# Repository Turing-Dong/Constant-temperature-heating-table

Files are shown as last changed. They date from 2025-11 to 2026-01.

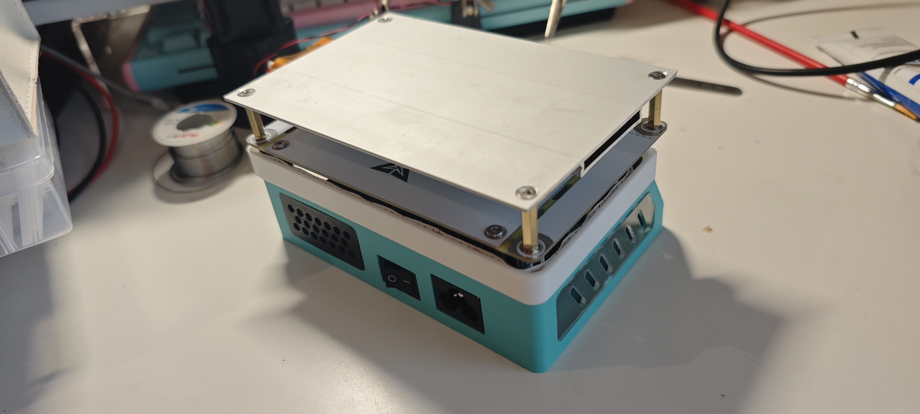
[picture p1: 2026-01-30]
project_v1.2/image/f8bacf540ac5dc9dfccfac3b2e75b12f.jpg

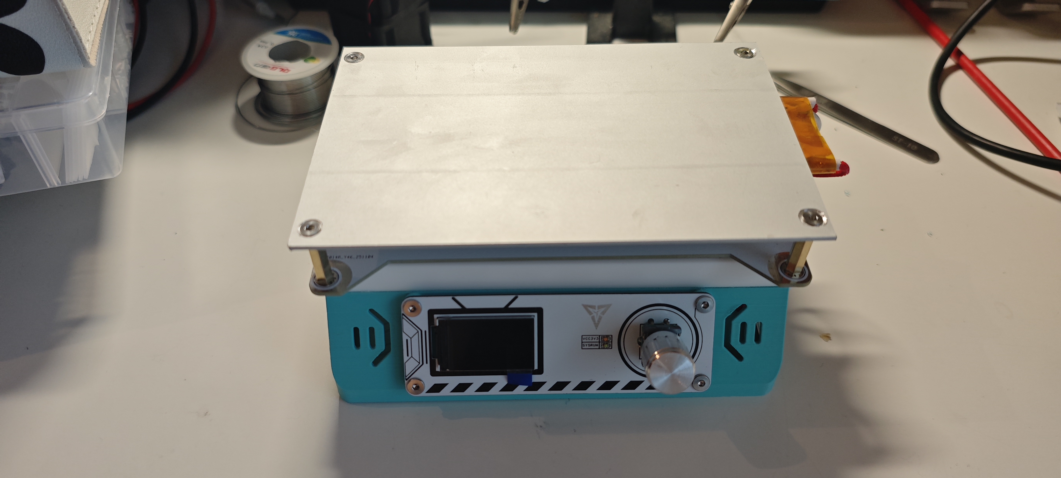
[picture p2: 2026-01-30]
project_v1.2/image/071cbeb4dcf4d1cab42405f28dda0755.jpg

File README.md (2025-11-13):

# Constant-temperature-heating-table
Heating table with warning light and temperature display.

The main feature of this project is that it beautifies its appearance compared to the traditional heating table, and adds RGB lights for warning on the periphery.

Note: 
1、It cannot be used for commercial use without my permission, otherwise legal responsibility will be pursued!
2、In addition, friends are also welcome to optimize and merge the project.

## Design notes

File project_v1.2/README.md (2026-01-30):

# Constant-temperature-heating-table
Heating table with warning light and temperature display.

The main feature of this project is that it beautifies its appearance compared to the traditional heating table, and adds RGB lights for warning on the periphery.

Note: 
1、It cannot be used for commercial use without my permission, otherwise legal responsibility will be pursued!
2、In addition, friends are also welcome to optimize and merge the project.

### Version Updated Record：

#### V1.0:

**1.Complete the basic functions(Temperature display, temperature setting, heating, light alarm).** 

#### V1.2:

**1.Improve the recognition effect of rotary encoder operations;** 

**2.Optimized the execution logic of the buzzer and changed to timer timing, non-blocking form;**

**3.Fixed the display bug of RGB lights.**

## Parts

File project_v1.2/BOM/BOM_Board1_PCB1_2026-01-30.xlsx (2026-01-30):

No. | Device | Footprint | Name | Designator | Quantity
1 | 贴片蜂鸣器 | BUZ-SMD_L9.6-W9.6-LS10.0-R | 贴片蜂鸣器 | BEEP | 1
2 | 0603N220J500 | C0603 | 22pF | C1 | 1
3 | 0603N220J500 | C0603 | 22pF | C2 | 1
4 | 100nF/25V | C0603 | 100nF | C3 | 1
5 | 100nF/25V | C0603 | 100nF | C4 | 1
6 | 100nF/25V | C0603 | 100nF | C5 | 1
7 | 100nF/25V | C0603 | 100nF | C6 | 1
8 | 100nF/25V | C0603 | 100nF | C7 | 1
9 | CAP_0603 | C0603 | 10uF | C12 | 1
10 | 150nF | CAP-TH_L13.0-W6.0-P10.00-D0.8 | 10nF | C13 | 1
11 | CAP_0603 | C0805 | 22uF | C16 | 1
12 | CAP_0603 | C0805 | 22uF | C17 | 1
13 | 0603 | C0603 | 100nF | C23 | 1
14 | 0603 | C0603 | 100nF | C24 | 1
15 | CAP_0603 | C0805 | 22uF | C25 | 1
16 | CAP_0603 | C0805 | 22uF | C26 | 1
17 | 0603 | C0603 | 100nF | C27 | 1
18 | 0603 | C0603 | 100nF | C28 | 1
19 | XH2.54-2PIN-直针 | CONN-TH_XH2.54-2P | XH2.54-2P | CN1 | 1
20 | 1N4148W_C81598 | SOD-123F_L2.7-W1.6-LS3.8-RD | 1N4148W | D1 | 1
21 | BZT52C3V0_C707127 | SOD-123_L2.7-W1.6-LS3.7-RD-1 | BZT52C3V0 | D2 | 1
22 | BZT52C3V0_C707127 | SOD-123_L2.7-W1.6-LS3.7-RD-1 | BZT52C3V0 | D3 | 1
23 | 2009T3.15A250V | FUSE-TH_L8.5-W4.0-P5.08-D0.6 | 2009T3.15A250V | F1 | 1
24 | FUSE | F1206 | FUSE | F2 | 1
25 | B02B-XARK-1(LF)(SN) | CONN-TH_2P-P2.50_C9900007036 | B02B-XARK-1(LF)(SN) | FAN | 1
26 | 52271-1869 | FPC-SMD_18P-P1.00_52271-1869 | 52271-1869 | FPC1 | 1
27 | GPHA101-0402A001A1BA | HDR-TH_4P-P2.54-V-M | GPHA101-0402A001A1BA | J1 | 1
28 | 5.08-3P直插式绿端子 | CONN-TH_3P-P5.08_KF2EDGV-5.08-3P | 5.08-3P直插式绿端子 | J3 | 1
29 | XH插座1*3P间距2.5mm直针, | CONN-TH_C722693 | XH插座1*3P | J4 | 1
30 | GPHA101-0402A001A1BA | HDR-TH_4P-P2.54-V-M | GPHA101-0402A001A1BA | J5 | 1
31 | KT-0603R | LED0603-RD | KT-0603R | LED2 | 1
32 | S8050 | SOT-23-3_L2.9-W1.3-P1.90-LS2.4-BR | S8050 | Q2 | 1
33 | AO3400 | SOT-23-3_L2.9-W1.3-P1.90-LS2.4-BL-2 | AO3400 | Q3 | 1
34 | 2N7002 | SOT-23-3_L2.9-W1.3-P1.90-LS2.4-BR | 2N7002 | Q4 | 1
35 | BT138-600E | TO-220-3_L10.2-W4.5-P2.54-L | BT138-600E | Q5 | 1
36 | ERJUP3J104V | R0603 | 10kΩ | R1 | 1
37 | ERJUP3J104V | R0603 | 10kΩ | R2 | 1
38 | ERJUP3J104V | R0603 | 0Ω | R3 | 1
39 | ERJUP3J104V | R0603 | 0Ω | R4 | 1
40 | ERJUP3J104V | R0603 | 0Ω | R5 | 1
41 | ERJUP3J104V | R0603 | 0Ω | R6 | 1
42 | ERJUP3J104V | R0603 | 1kΩ | R7 | 1
43 | Res_0603 | R0603 | 10R | R13 | 1
44 | Res_0603 | R0603 | 4.7k | R14 | 1
45 | Res_0603 | R0603 | 10k | R15 | 1
46 | Res_0603 | R0603 | 4.7K | R16 | 1
47 | Res_0603 | R0603 | 10 | R17 | 1
48 | Res_0603 | R0603 | 10R | R18 | 1
49 | Res_0603 | R0603 | 100R | R19 | 1
50 | Res_0603 | R2512 | 360R | R20 | 1
51 | Res_0603 | R2512 | 360R | R21 | 1
52 | Res_0603 | R1206 | 39 | R22 | 1
53 | Res_0603 | R0603 | 1K | R23 | 1
54 | Res_0603 | R0603 | 1K | R24 | 1
55 | Res_0603 | R0603 | 1K | R25 | 1
56 | Res_0603 | R0603 | 20K | R26 | 1
57 | Res_0603 | R0603 | 1K | R27 | 1
58 | Res_0603 | R0603 | 130K | R28 | 1
59 | Res_0603 | R0603 | 0R | R29 | 1
60 | Res_0603 | R0603 | 0R | R30 | 1
61 | 轻触按键3*6*2.5 | SW-SMD_L6.0-W3.6-LS8.0 | 轻触按键3*6*2.5 | RST | 1
62 | KCD1-101-2P | SW-TH_KCD1-101-2P | KCD1-101-2P | SW3 | 1
63 | STM32F103C8T6 | LQFP-48_L7.0-W7.0-P0.50-LS9.0-BL | STM32F103C8T6 | U1 | 1
64 | HLK-10M05 | PWRM-TH_HLK-10M05 | HLK-10M05 | U5 | 1
65 | TypeC-16PIN | USB-C-SMD_TYPE-C-6PIN-2MD-073 | TypeC-16PIN | U6 | 1
66 | MOC3041SR2M | SOP-6_L8.5-W6.4-P2.54-LS9.2-BL | MOC3041SR2M | U7 | 1
67 | 23*16*50 H型散热片 | HEATSINK-TH_L23.4-W15.2-P17.8_C9900022558 | 23*16*50 H型散热片 | U8 | 1
68 | LM358 | SOP-8_L5.0-W4.0-P1.27-LS6.0-BL | LM358 | U10 | 1
69 | SGM3157 | SC-70-6_L2.2-W1.3-P0.65-LS2.1-BL | SGM3157 | U11 | 1
70 | RT9013-3.3GB | SOT-23-5_L2.9-W1.6-P0.94-LS2.8-BL | RT9013-3.3GB | U12 | 1
71 | RT9013-3.3GB | SOT-23-5_L2.9-W1.6-P0.94-LS2.8-BL | RT9013-3.3GB | U13 | 1
72 | DB-6-1P4P3_C42376624 | CONN-TH_DB-6-1P4P3 | DB-6-1P4P3 | U14 | 1
73 | X322516MLB4SI | OSC-SMD_4P-L3.2-W2.5-BL | 16MHz | X1 | 1

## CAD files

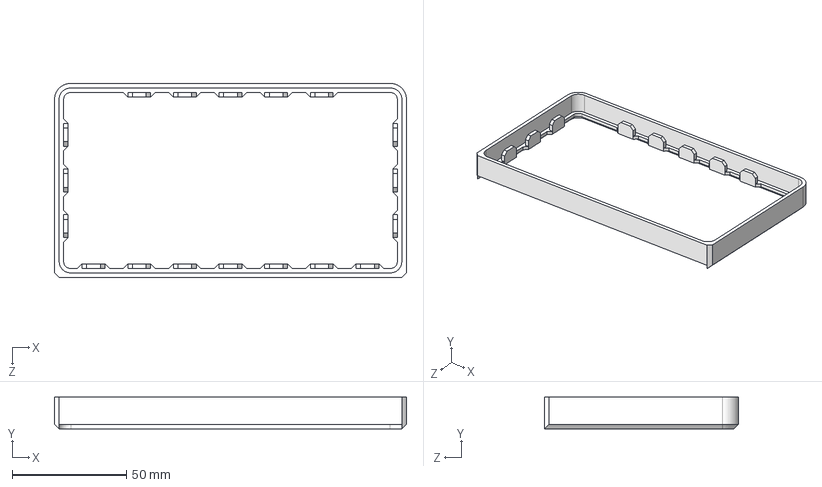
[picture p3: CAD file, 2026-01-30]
project_v1.2/shapeFile/RGB框2.STEP
154.2 x 14.0 x 85.0 mm

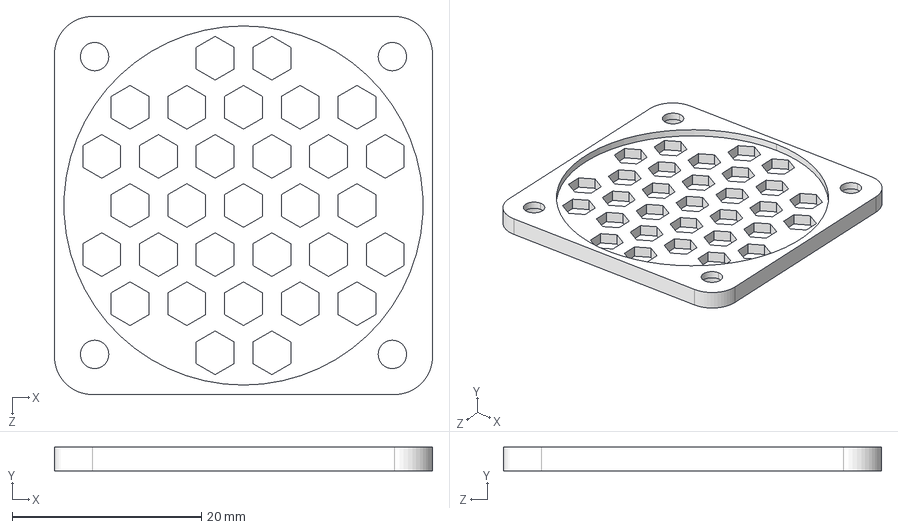
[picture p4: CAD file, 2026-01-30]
project_v1.2/shapeFile/电机罩.STEP
40.0 x 2.50 x 40.0 mm

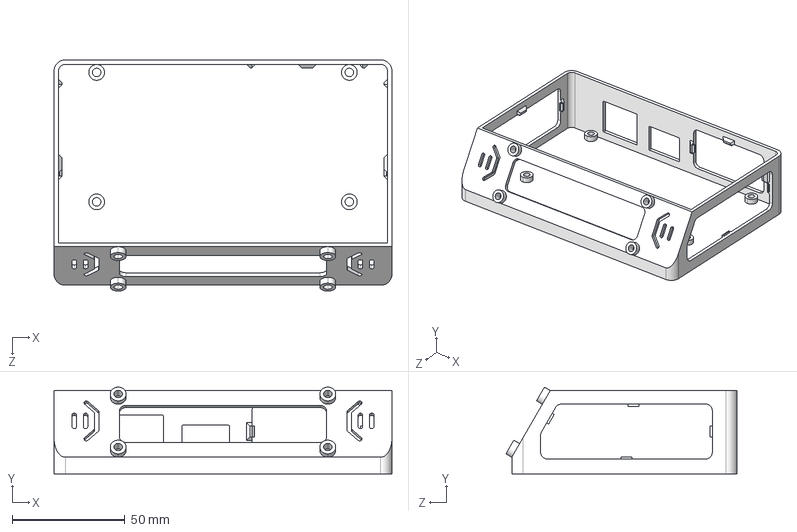
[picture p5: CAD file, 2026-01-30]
project_v1.2/shapeFile/底3.STEP
150.0 x 38.5 x 102.6 mm

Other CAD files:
project_v1.2/shapeFile/cut.DWG

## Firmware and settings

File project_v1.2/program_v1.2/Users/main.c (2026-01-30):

#include "./SYSTEM/sys/sys.h"
#include "./SYSTEM/usart/usart.h"
#include "./SYSTEM/delay/delay.h"
#include "./BSP/RGB/rgb.h"
#include "./BSP/LED/led.h"
#include "./BSP/BEEP/beep.h"
#include "./BSP/LCD/lcd_init.h"
#include "./BSP/LCD/lcd.h"
#include "./BSP/LCD/pic.h"
#include "./BSP/FAN/fan.h"
#include "./BSP/KEY/key.h"
#include "./BSP/EXTI/exti.h"
#include "./BSP/TIM/gtim.h"
#include "./BSP/ADC/adc.h"
#include "./BSP/GLOBALS/globals.h"
#include <math.h>

#define SYS_NORMAL 1
#define SYS_WORKING 2

// 在全局变量区域添加NTC参数 (根据实际测量值修正)
#define NTC_BETA 3950           // NTC热敏电阻的B值
#define NTC_R25 92180           // 25°C时的电阻值(根据实际测量为92.18K)
#define NTC_T25 298.15          // 25°C对应的开尔文温度

#define TEMP_SMOOTHING_SIZE 10  // 平滑窗口大小
double temp_buffer[TEMP_SMOOTHING_SIZE] = {0};  // 温度缓冲区
uint8_t temp_buffer_index = 0;                  // 缓冲区索引
uint8_t temp_buffer_full = 0;                   // 缓冲区是否已满标志

// 在全局变量区域添加RGB状态机相关变量
typedef enum {
    RGB_STATE_RAINBOW,      // 彩虹流水灯状态
    RGB_STATE_BLUE,         // 冷蓝色色状态 (加热时温度<40°C)
    RGB_STATE_YELLOW_GREEN, // 黄绿色色状态 (40-70°C)
    RGB_STATE_YELLOW,       // 黄色状态 (70-100°C)
    RGB_STATE_ORANGE,       // 橙色状态 (100-150°C)
    RGB_STATE_RED,          // 红色状态 (150-200°C)
    RGB_STATE_PURPLE        // 紫色状态 (>200°C)
} RGB_State_TypeDef;

RGB_State_TypeDef rgb_current_state = RGB_STATE_RAINBOW;  // 当前RGB状态
uint8_t rgb_state_changed = 1;  // 状态改变标志，初始设为1以触发首次写入

//数据表
//const unsigned int data_x[101] = 
//{
//	  0,  3,  6,  9, 12, 15, 18, 21, 24, 27,
//	 30, 33, 36, 39, 42, 45, 48, 51, 54, 57,
//	 60, 63, 66, 69, 72, 75, 78, 81, 84, 87,
//	 90, 93, 96, 99,102,105,108,111,114,117,
//	120,123,126,129,132,135,138,141,144,147,
//	150,153,156,159,162,165,168,171,174,177,
//	180,183,186,189,192,195,198,201,204,207,
//	210,213,216,219,222,225,228,231,234,237,
//	240,243,246,249,252,255,258,261,264,267,
//	270,273,276,279,282,285,288,291,294,297,
//	300
//};
//const float data_y[101] =
//{
//	325.0790,280.4187,242.2063,209.5278,181.5805,157.6669,137.1862,119.6241,104.5422, 91.5683,
//	 80.3868, 70.7309, 62.3750, 55.1284, 48.8297, 43.3428, 38.5520, 34.3596, 30.6826, 27.4504,
//	 24.6029, 22.0888, 19.8645, 17.8924, 16.1403, 14.5808, 13.1898, 11.9470, 10.8346,  9.8295,
//	  8.9273,  8.1205,  7.3983,  6.7509,  6.1697,  5.6471,  5.1764,  4.7514,  4.3669,  4.0183,
//	  3.7015,  3.4127,  3.1442,  2.8908,  2.6606,  2.4517,  2.2623,  2.0906,  1.9348,  1.7934,
//	  1.6649,  1.5480,  1.4415,  1.3441,  1.2551,  1.1733,  1.0981,  1.0286,  0.9643,  0.9016,
//	  0.8423,  0.7877,  0.7375,  0.6913,  0.6489,  0.6100,  0.5742,  0.5412,  0.5108,  0.4827,
//	  0.4566,  0.4324,  0.4099,  0.3887,  0.3689,  0.3502,  0.3312,  0.3134,  0.2966,  0.2809,
//	  0.2662,  0.2524,  0.2395,  0.2275,  0.2162,  0.2056,  0.1957,  0.1864,  0.1776,  0.1694,
//	  0.1616,  0.1542,  0.1473,  0.1407,  0.1345,  0.1285,  0.1228,  0.1174,  0.1122,  0.1071,
//	  0.10233
//};

struct struct_adc_data
{
	uint32_t adc_data_adc0;
	uint32_t adc_data_adc1;
	uint8_t adc_channel;
	/* data */
};

struct pid_parameter
{
	float pid_p;
	float pid_i;
	float pid_d;
	float pre_err;
	float last_err;
	float pid_pout;
	float pid_iout;
	float pid_dout;
	int pid_out;
	int pid_out_max;
};
typedef struct pid_parameter* pid_pointer;

//extern unsigned char gImage_bg;
double temp_calcu(unsigned int x1,double y1,unsigned int x2,double y2,double res_val);
double pre_temp(double res_val);
double get_preres(double vadc);

struct struct_adc_data myadc_data;
struct pid_parameter my_pid;
pid_pointer my_pid_pointer = &my_pid;

uint8_t g_BeepFlag = 0;
uint8_t g_UpdateFlag = 1;
double pre_temperature = 0;
uint32_t OUT_PWM = 40;
// 在全局变量区域添加以下变量
uint32_t rainbow_index = 0;  // 流水灯索引
uint32_t rainbow_timer = 0; // 流水灯定时器
uint32_t led_timer;
Color_TypeDef temp1;
Color_TypeDef temp2;
Color_TypeDef temp3;
Color_TypeDef temp4;
Color_TypeDef temp5;
Color_TypeDef temp6;        // 白色状态颜色

double smooth_temperature(double raw_temp);     //温度平滑处理
void update_display(void);                      // 更新显示
void adc_auto_channel(void);                    // 自动选择ADC通道
void color_init(void);                          // 初始化RGB灯
void mypid_init(void);                          // 初始化PID参数
void pid_calculate(void);                       // PID计算
void rgb_change(void);                          // RGB灯颜色渐变
void draw_table_frame(void);                    // 绘制表格框架

int main(void)
{
    u16 PRE_TEMP;
    double vadc = 0;
    double pre_res = 0;
    HAL_Init();                                             /* 初始化HAL库 */
    //sys_stm32_clock_init(RCC_PLL_MUL9);                   /* 设置时钟, 72Mhz */
    sys_stm32_clock_init(RCC_PLL_MUL4);
		beep_init();
    delay_init(72);                                         /* 延时初始化 */
    usart_init(115200);                                     /* 初始化串口 */
    led_init();                                             /* 初始化LED */
    gtim_timx_pwm_chy_init(500 - 1, 72 - 1);                /* 1Mhz的计数频率,2Khz的PWM. */
    __HAL_TIM_SET_COMPARE(&g_timx_pwm_chy_handle, GTIM_TIMX_PWM_CHY, 500 - 0*5);
    fan_init();
    key_init();
    seg_init();
    exti_init();
    adc_init();
    
    LCD_Init();                                             // LCD初始化
    LCD_Fill(0, 0, LCD_W, LCD_H, BLACK);                    // 填充背景色
    
    // 绘制表格框架
    draw_table_frame();
    
    // 显示固定标签文本
    LCD_ShowString(10, 10, "STAT:", CYAN, BLACK, 32, 0);
		LCD_ShowString(10, 53, "SET:", LIGHTBLUE, BLACK, 32, 0);
		LCD_ShowString(10, 96, "TEMP:", GREEN, BLACK, 32, 0);
    
    WS2812B_Init();	
    color_init();
    mypid_init();
    FAN(0);
    WS2812B_FillColor(0, 27, &temp1);
    WS2812B_RefreshPixel();
    
		uint32_t last_sw_time = 0;
    uint32_t last_enc_time = 0;
		
    while (1)
    {
				// === 1. 处理编码器增量 ===
        if (enc_delta != 0) {
            int16_t delta = 0;
						
					// 临界区保护
						HAL_NVIC_DisableIRQ(EXTI9_5_IRQn);   // 关编码器中断（A相）
						HAL_NVIC_DisableIRQ(EXTI15_10_IRQn);   // 关编码器中断（B相）
						delta = enc_delta;
						enc_delta = 0;
						HAL_NVIC_EnableIRQ(EXTI9_5_IRQn);
						HAL_NVIC_EnableIRQ(EXTI15_10_IRQn);
            
            // 更新参数（带限幅）
            if (delta > 0 && temp_set < 300) temp_set++;
            if (delta < 0 && temp_set > 0)   temp_set--;

            beep_req = 1;     // 请求蜂鸣器
            update_req = 1;   // 请求刷新显示
        }

        // === 2. 处理按键消抖（软件消抖，精准可控）===
        if (sw_press) {
            if (HAL_GetTick() - last_sw_time > 20) { // 20ms去抖
                if (HAL_GPIO_ReadPin(EN_GPIO_PORT, EN_SW_GPIO_PIN) == 0) {
                    // 确认为有效按键
                    if (SYS_STATE == SYS_NORMAL) {
                        SYS_STATE = SYS_WORKING;
                    } else {
                        SYS_STATE = SYS_NORMAL;
                    }
                    beep_req = 1;     // 按键也响一声
                    update_req = 1;
                }
                sw_press = 0; // 清标志
            }
        } else {
            last_sw_time = HAL_GetTick();
        }

        // === 3. 执行蜂鸣器请求（非阻塞）===
        if (beep_req) {
            Buzzer_Tone(10); // 调用我们之前设计的非阻塞函数
            beep_req = 0;
        }
				
        adc_auto_channel();
        
        if(myadc_data.adc_channel == 0)
        {
            PRE_TEMP = myadc_data.adc_data_adc0;
            vadc = PRE_TEMP*3.3/4096.0;
        }
        else
        {
            PRE_TEMP = myadc_data.adc_data_adc1;
            vadc = PRE_TEMP*3.3/4096.0/21.0;
        }
		
        pre_res = get_preres(vadc);
        
        // 修正电阻值范围检查 - 更合理的范围
        if(pre_res < 100 || pre_res > 5000000) {
            // 不要强制设置默认值，而是允许一定范围内的异常值
            // 只在明显错误时才使用默认值
            if(pre_res < 10 || pre_res > 10000000) {
                pre_res = 92180; // 设置为25°C时的实际阻值
            }
        }
        
        pre_temperature = pre_temp(pre_res);  // 使用新的NTC B值公式计算温度
        
        // 移除过于严格的温度范围检查，允许温度正常变化
        // 只在明显错误时进行修正
        if(pre_temperature < -100 || pre_temperature > 600) {
            pre_temperature = 25; // 只在极端异常时设置默认值
        }
        
        pre_temperature = smooth_temperature(pre_temperature);  // 添加平滑处理
        
		// 在主循环中添加以下代码（放在while(1)循环内合适位置）
		if(pre_temperature <= 40)
		{
			if(HAL_GetTick() - rainbow_timer > 20) // 每20ms更新一次流水灯
			{
				rainbow_timer = HAL_GetTick();
				rainbow_index++;
				//rainbow_index = (rainbow_index + 1) % 256;
			}
		}
		
    // 使用新的更新显示函数
		update_display();
        
        if(HAL_GetTick() - led_timer > 200) // 每200ms更新一次LED
		{
			led_timer = HAL_GetTick();
			LED0_TOGGLE();
		}
        if(SYS_STATE == SYS_NORMAL)
        {
            __HAL_TIM_SET_COMPARE(&g_timx_pwm_chy_handle, GTIM_TIMX_PWM_CHY, 500 - 0*5);
            if(pre_temperature > 40)
            {
                //打开风扇
                FAN(1);
            }
            else
            {
                //关闭风扇
                FAN(0);
            }
        }
        else if(SYS_STATE == SYS_WORKING)
        {
            FAN(0);
            pid_calculate();
            __HAL_TIM_SET_COMPARE(&g_timx_pwm_chy_handle, GTIM_TIMX_PWM_CHY, 500 - my_pid_pointer->pid_out*5);
        }
        delay_ms(1);
    }
}

//ADC通道自动切换且读取ADC数据函数
//ADC通道自动切换且读取ADC数据函数
void adc_auto_channel(void)
{
	uint32_t data = 0;
	SEG_ADC0;
	data = adc_get_result_average(ADC_CHANNEL_8,5);
	// 修改判断条件，使用更合理的阈值
	if(data >= 200)  // 原来是100，改为200更合理
	{
		myadc_data.adc_channel = 0;
		myadc_data.adc_data_adc0 = data;
	}
	else
	{
		SEG_ADC1;
		data = adc_get_result_average(ADC_CHANNEL_8,5);
		myadc_data.adc_channel = 1;
		myadc_data.adc_data_adc1 = data;
	}
}

//通过adc的电压值得到当前的电阻值
double get_preres(double vadc)
{
    double pre_res = 0;
    
    // 防止除零错误和无效值
    if(vadc >= 3.29) vadc = 3.29;
    if(vadc <= 0.001) vadc = 0.001;
    
    // 根据分压电路计算NTC电阻值
    // 电路连接: 3.3V -- 130K电阻 -- ADC点 -- NTC热敏电阻 -- GND
    // Vadc = 3.3 * (NTC_R / (NTC_R + 130K))
    // NTC_R = 130K * (Vadc / (3.3 - Vadc))
    pre_res = 130000.0 * vadc / (3.3 - vadc);
    return pre_res;
}

// 使用标准的NTC B值公式计算温度
// 通过输入当前读取的电阻值获取当前的温度 (使用NTC B值公式)
double pre_temp(double res_val)
{
    double temperature = 0;
    double lnR;
    double tempK;
    
    // 防止无效值
    if(res_val <= 0) res_val = 1;
    if(res_val > 10000000) res_val = 10000000; // 防止过大值
    
    // 使用NTC热敏电阻的标准B值公式:
    // 1/T = 1/T0 + ln(R/R0)/B
    // T = 1/(1/T0 + ln(R/R0)/B) - 273.15 (转换为摄氏度)
    
    // 根据实际测量修正参数
    const double ACTUAL_R25 = 92180.0;  // 25°C时实际测量的阻值 92.18K
    const double BETA = 3950.0;         // B值
    const double T25 = 298.15;          // 25°C对应的开尔文温度
    
    lnR = log(res_val / ACTUAL_R25);    // ln(R/R0)
    tempK = 1.0 / (1.0/T25 + lnR/BETA); // 开尔文温度
    temperature = tempK - 273.15;       // 转换为摄氏度
    
    // 限制温度范围，防止异常值
    if(temperature < -50) temperature = -50;
    if(temperature > 500) temperature = 500;
    
    return temperature;
}
void mypid_init(void)
{
	my_pid_pointer->pre_err = 0;
	my_pid_pointer->last_err = 0;
	my_pid_pointer->pid_pout = 0;
	my_pid_pointer->pid_iout = 0;
	my_pid_pointer->pid_dout = 0;
	my_pid_pointer->pid_out = 0;
	my_pid_pointer->pid_out_max = 100;  // 增加最大输出值，原来是50可能太小
	my_pid_pointer->pid_p = 0.3;        // 增加比例系数，原来是0.1可能太小
	my_pid_pointer->pid_i = 0.01;       // 添加积分系数
	my_pid_pointer->pid_d = 0.05;       // 微分系数可以保持不变
}
void pid_calculate(void)
{
	my_pid_pointer->last_err = my_pid_pointer->pre_err;
	my_pid_pointer->pre_err = temp_set - pre_temperature;
	my_pid_pointer->pid_pout = my_pid_pointer->pre_err * my_pid_pointer->pid_p;
	my_pid_pointer->pid_dout = my_pid_pointer->pid_d * (my_pid_pointer->pre_err - my_pid_pointer->last_err);
	my_pid_pointer->pid_out = my_pid_pointer->pid_pout + my_pid_pointer->pid_dout;
	if(my_pid_pointer->pid_dout > my_pid_pointer->pid_out_max)
		my_pid_pointer->pid_out = my_pid_pointer->pid_out_max;
	else if(my_pid_pointer->pid_out < 0)
		my_pid_pointer->pid_out = 0;
}
void color_init(void){
	temp1.R = 0x7C;
	temp1.G = 0xfC;
	temp1.B = 0x00;  //紫色

	temp2.R = 0x87;
	temp2.G = 0xCE;
	temp2.B = 0xFA;  // 冰蓝色 (Light Sky Blue)

	temp3.R = 0x9A;
	temp3.G = 0xCD;
	temp3.B = 0x32;  // 黄绿色 (Yellow-Green)

	temp4.R = 0xFF;
	temp4.G = 0xFF;
	temp4.B = 0x00;  // 黄色
    
    // 橙色保持不变
    temp5.R = 0xFF;
	temp5.G = 0x61;
	temp5.B = 0x00; // 橙色

    // 红色 (使用原来的temp6位置)
    temp6.R = 0xFF;
	temp6.G = 0x00;
	temp6.B = 0x00; // 红色
}
// 添加新的颜色生成函数
void generate_rainbow_color(uint8_t position, Color_TypeDef *color)
{
    uint8_t hue = position % 27; // 修改为27，与实际灯数匹配
    
    // 将27个位置均匀分布在HSB色彩环上
    if(position < 5) {
        // 红到黄过渡 (约0-60度)
        color->R = 0xFF;
        color->G = position * 51;  // 0-255
        color->B = 0x00;
    }
    else if(position < 9) {
        // 黄到绿过渡 (约60-120度)
        color->R = 0xFF - ((position-5) * 64); // 255-0
        color->G = 0xFF;
        color->B = 0x00;
    }
    else if(position < 14) {
        // 绿到青过渡 (约120-180度)
        color->R = 0x00;
        color->G = 0xFF;
        color->B = (position-9) * 51; // 0-255
    }
    else if(position < 18) {
        // 青到蓝过渡 (约180-240度)
        color->R = 0x00;
        color->G = 0xFF - ((position-14) * 64); // 255-0
        color->B = 0xFF;
    }
    else if(position < 23) {
        // 蓝到紫过渡 (约240-300度)
        color->R = (position-18) * 51; // 0-255
        color->G = 0x00;
        color->B = 0xFF;
    }
    else {
        // 紫到红过渡 (约300-360度)
        color->R = 0xFF;
        color->G = 0x00;
        color->B = 0xFF - ((position-23) * 51); // 255-0
    }
}

// 修改rgb_change函数为基于状态机的版本
void rgb_change(void)
{
    RGB_State_TypeDef new_state;
    
    // 根据温度和系统状态确定目标状态
    if(SYS_STATE == SYS_NORMAL && pre_temperature <= 40)
    {
        new_state = RGB_STATE_RAINBOW;        // 不加热且温度≤40°C，显示彩虹流水灯
    }
    else if(SYS_STATE == SYS_WORKING && pre_temperature < 40)
    {
        new_state = RGB_STATE_BLUE;           // 加热且温度<40°C，显示冰蓝色
    }
    else if(pre_temperature >= 40 && pre_temperature <= 70)
    {
        new_state = RGB_STATE_YELLOW_GREEN;   // 40-70°C，显示浅黄绿色
    }
    else if(pre_temperature > 70 && pre_temperature <= 100)
    {
        new_state = RGB_STATE_YELLOW;         // 70-100°C，显示黄色
    }
    else if(pre_temperature > 100 && pre_temperature <= 150)
    {
        new_state = RGB_STATE_ORANGE;         // 100-150°C，显示橙色
    }
    else if(pre_temperature > 150 && pre_temperature <= 200)
    {
        new_state = RGB_STATE_RED;            // 150-200°C，显示红色
    }
    else
    {
        new_state = RGB_STATE_PURPLE;         // >200°C，显示紫色
    }
    
    // 检查状态是否发生变化
    if(new_state != rgb_current_state)
    {
        rgb_current_state = new_state;
        rgb_state_changed = 1;
    }
    
    // 根据状态执行相应操作
    switch(rgb_current_state)
    {
        case RGB_STATE_RAINBOW:
            // 彩色流水灯效果 - 只有在SYS_STATE == SYS_NORMAL且温度<=40时才启用
            if(rgb_state_changed || 1) // 总是更新以保持动画效果
            {
                for(int i = 0; i < 27; i++)
                {
                    uint8_t color_position = (i + rainbow_index) % 27;
                    Color_TypeDef color;
                    generate_rainbow_color(color_position, &color);
                    Copy_Color(&PixelBuf[i], &color);
                }
                WS2812B_RefreshPixel();
                rgb_state_changed = 0;
            }
            break;
            
        case RGB_STATE_BLUE:
            // 冰蓝色状态 - 加热时温度<40°C
            if(rgb_state_changed)
            {
                WS2812B_FillColor(0, 27, &temp2);  // 使用冰蓝色
                WS2812B_RefreshPixel();
                rgb_state_changed = 0;
            }
            break;
            
        case RGB_STATE_YELLOW_GREEN:
            // 浅黄绿色状态 - 40-70°C
            if(rgb_state_changed)
            {
                WS2812B_FillColor(0, 27, &temp3);  // 使用浅黄绿色
                WS2812B_RefreshPixel();
                rgb_state_changed = 0;
            }
            break;
            
        case RGB_STATE_YELLOW:
            // 黄色状态 - 70-100°C
            if(rgb_state_changed)
            {
                WS2812B_FillColor(0, 27, &temp4);  // 使用黄色
                WS2812B_RefreshPixel();
                rgb_state_changed = 0;
            }
            break;
            
        case RGB_STATE_ORANGE:
            // 橙色状态 - 100-150°C
            if(rgb_state_changed)
            {
                WS2812B_FillColor(0, 27, &temp5);  // 使用橙色
                WS2812B_RefreshPixel();
                rgb_state_changed = 0;
            }
            break;
            
        case RGB_STATE_RED:
            // 红色状态 - 150-200°C
            if(rgb_state_changed)
            {
                WS2812B_FillColor(0, 27, &temp6);  // 使用红色
                WS2812B_RefreshPixel();
                rgb_state_changed = 0;
            }
            break;
            
        case RGB_STATE_PURPLE:
            // 紫色状态 - >200°C
            if(rgb_state_changed)
            {
                // 创建一个新的Color_TypeDef变量用于紫色
                Color_TypeDef purple_color;
                purple_color.R = 0x80;
                purple_color.G = 0x00;
                purple_color.B = 0x80; // 紫色
                
                WS2812B_FillColor(0, 27, &purple_color);
                WS2812B_RefreshPixel();
                rgb_state_changed = 0;
            }
            break;
            
        default:
            break;
    }
}

// 新增函数：绘制指定宽度的水平线（加粗线条）
void draw_thick_hline(u16 x1, u16 y, u16 x2, u16 color, u8 thickness)
{
    u8 i;
    for(i = 0; i < thickness; i++)
    {
        LCD_DrawLine(x1, y + i, x2, y + i, color);
    }
}

// 新增函数：绘制指定宽度的垂直线（加粗线条）
void draw_thick_vline(u16 x, u16 y1, u16 y2, u16 color, u8 thickness)
{
    u8 i;
    for(i = 0; i < thickness; i++)
    {
        LCD_DrawLine(x + i, y1, x + i, y2, color);
    }
}

// 新增函数：绘制指定宽度的矩形框（加粗线条）
void draw_thick_rectangle(u16 x1, u16 y1, u16 x2, u16 y2, u16 color, u8 thickness)
{
    u8 i;
    for(i = 0; i < thickness; i++)
    {
        LCD_DrawRectangle(x1 + i, y1 + i, x2 - i, y2 - i, color);
    }
}

// 修改函数：绘制带边框的表格区域（加粗线条，3像素宽，只显示三行）
void draw_table_frame(void)
{
    // 绘制外边框 (3像素宽)
    draw_thick_rectangle(2, 2, LCD_W-2, LCD_H-2, WHITE, 3);
    
    // 绘制水平分割线 (3像素宽，将屏幕分为三行)
    draw_thick_hline(2, 45, LCD_W-2, WHITE, 3);    // 第一行分割线（状态）
    draw_thick_hline(2, 90, LCD_W-2, WHITE, 3);   // 第二行分割线（设定温度）
    
    // 绘制竖直分割线 (3像素宽)
    draw_thick_vline(90, 2, LCD_H-2, WHITE, 3); // 标签和数值之间的分割线
}

// 更新显示函数，包括界面框架和数据显示（每行使用不同颜色）
void update_display(void)
{
		if(update_req == 1)
		{
				update_req = 0;
				// 更新状态显示（第一行，使用红色）
				if(SYS_STATE == SYS_NORMAL)
				{
						LCD_ShowString(100, 10, "OFF", CYAN, BLACK, 32, 0);
				}
				else if(SYS_STATE == SYS_WORKING)
				{
						LCD_ShowString(100, 10, "ON ", CYAN, BLACK, 32, 0);
				}
				
				// 更新设定温度显示（第二行，使用浅蓝色）
				LCD_ShowIntNum(100, 53, temp_set, 3, LIGHTBLUE, BLACK, 32);
				LCD_ShowString(100 + 3*16, 53, " C", LIGHTBLUE, BLACK, 32, 0);  // 添加温度单位（空格+C）
		}
    
    // 更新当前温度显示（第三行，使用绿色）
    //LCD_ShowFloatNum1(100, 96, pre_temperature, 5, GREEN, BLACK, 32);
    LCD_ShowIntNum(100, 96, (int)pre_temperature, 3, GREEN, BLACK, 32);
    LCD_ShowString(100 + 3*16, 96, " C", GREEN, BLACK, 32, 0);  // 添加温度单位（空格+C）
    
    // 更新RGB灯显示
    rgb_change();
}

/**
 * @brief  对温度值进行平滑处理，使用移动平均算法
 * @param  raw_temp: 原始温度值
 * @retval 平滑后的温度值
 */
double smooth_temperature(double raw_temp)
{
    static double sum = 0;
    double smoothed_temp;
    
    // 将新值添加到缓冲区，并更新索引
    sum -= temp_buffer[temp_buffer_index];  // 从总和中减去即将被替换的旧值
    temp_buffer[temp_buffer_index] = raw_temp;  // 存储新值
    sum += raw_temp;  // 将新值加入总和
    
    // 更新索引
    temp_buffer_index++;
    if(temp_buffer_index >= TEMP_SMOOTHING_SIZE)
    {
        temp_buffer_index = 0;
        temp_buffer_full = 1;  // 标记缓冲区已满
    }
    
    // 计算平均值
    if(temp_buffer_full)
    {
        // 缓冲区已满，使用完整窗口大小计算平均值
        smoothed_temp = sum / TEMP_SMOOTHING_SIZE;
    }
    else
    {
        // 缓冲区未满，使用当前实际存储的数据数量计算平均值
        smoothed_temp = sum / (temp_buffer_index == 0 ? TEMP_SMOOTHING_SIZE : temp_buffer_index);
    }
    
    return smoothed_temp;
}
